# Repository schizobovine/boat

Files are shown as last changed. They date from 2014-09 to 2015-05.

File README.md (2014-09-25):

Battery Operated Arduino Thermometer (B.O.A.T.)
==============

Similar to Moteino/Anarduino, an Arduino-compatiblish uC board with onboard
RFM69CW, SMA edge connector, and i2c thermometer chip. Powered by CR2032
batter. No onboard voltage regulation, so don't plug into 5V unless you need a
doorstop (the ATMega will be fine, but the wireless card and thermometer are
only specced for 3.6V max).

Yes, there are many Arduino-based wireless sensor projects out there. Most use
2.4GHz radios, however, and that's getting to be an awful crowded band,
especially if one lives in an apartment building. To avoid making that even
worse, I choose to use one of the other ISM bands, specifically 433MHz. This is
normally used for stuff like garage door openers and the like. (Also military
radar, which makes for some hilarious anecdotes).

Anyway, I decided to build my own board for this, even if other designs exist
that are probably better in just about every way. But this one is my own
special snowflake. It even has a cow on it! (Don't judge me.)

Licensed under the Creative Commons Attribution-ShareAlike License
(CC-BY-SA-4.0)

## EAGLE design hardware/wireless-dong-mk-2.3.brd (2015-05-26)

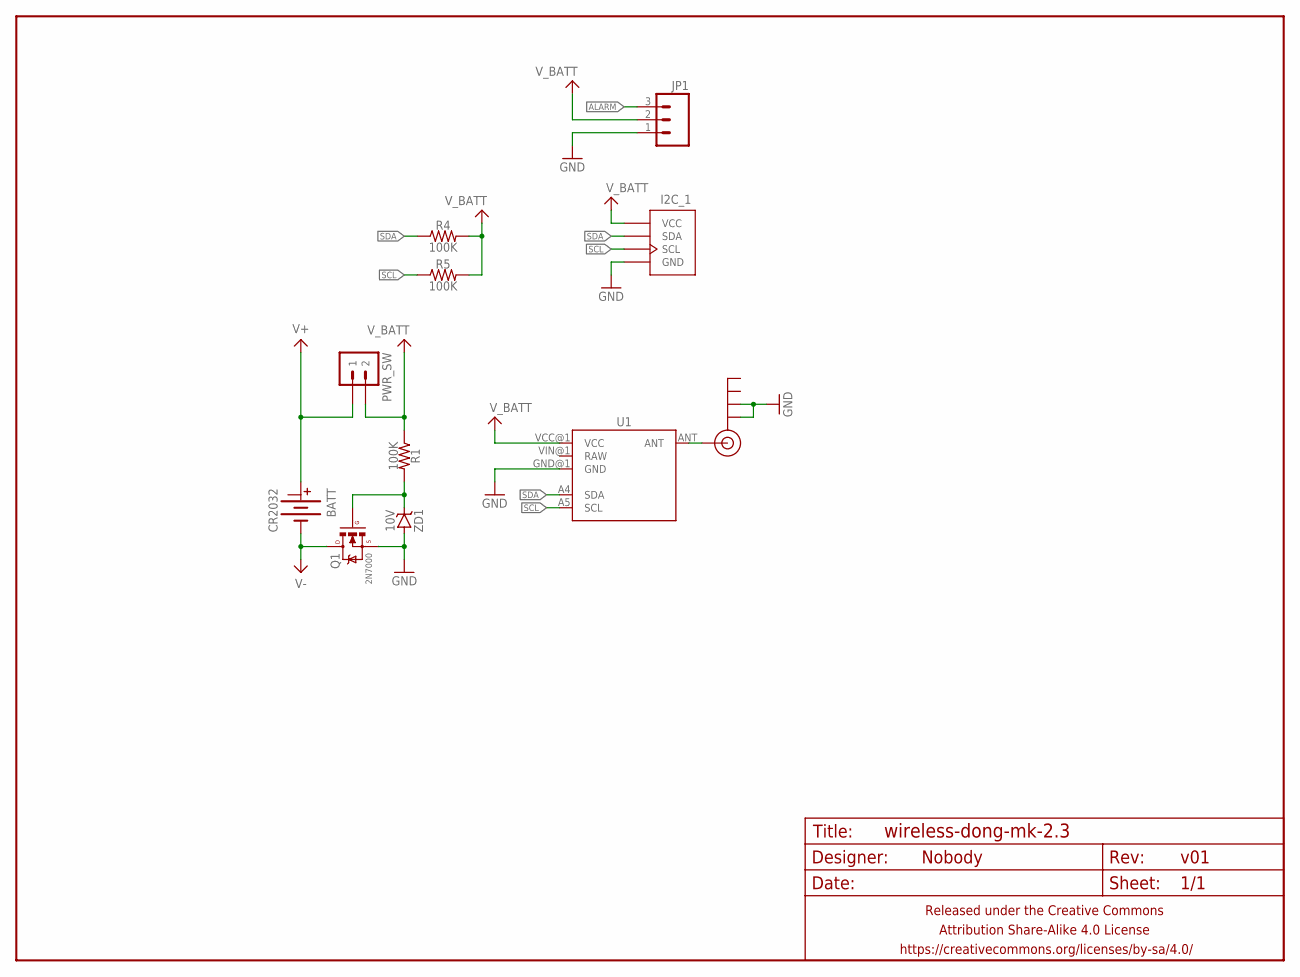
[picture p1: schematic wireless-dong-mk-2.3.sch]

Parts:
ANT: SMA_EDGE; SMA-EDGE
BATT: CR2032; BATTCON_20MM_MINE_STAHPIT
FRAME1: FRAME-LETTERNO_PACKAGE; DUMMY
I2C_1: M04-I2CJST-4-PH-RA-CENTERED; 1X04-JST-PH-RA-PTH-I2C-CENTERED
JP1: M03JST-PTH; JST-3-PH-RA-PTH
PWR_SW: M02PTH-CENTERED; 1X02-CENTER
Q1: 2N7000; SOT23
R1, R4, R5: 100K; R0805
U1: MOTEINO_BOAT
ZD1: 10V; SOT23

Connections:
ALARM: JP1.3
GND: ANT.GND@0 (GND), ANT.GND@1 (GND), I2C_1.1 (GND), JP1.1, Q1.2 (S), U1.GND@1 (GND), ZD1.1 (A), ZD1.2 (A)
unnamed: Q1.1 (G), R1.2, ZD1.3 (C)
unnamed: ANT.SIG (SIGNAL), U1.ANT
SCL: I2C_1.4 (SCL), R5.1, U1.A5 (SCL)
SDA: I2C_1.3 (SDA), R4.1, U1.A4 (SDA)
V+: BATT.TOP@1 (+), PWR_SW.1
V-: BATT.BOTTOM (-), Q1.3 (D)
V_BATT: I2C_1.2 (VCC), JP1.2, PWR_SW.2, R1.1, R4.2, R5.2, U1.VCC@1 (VCC)

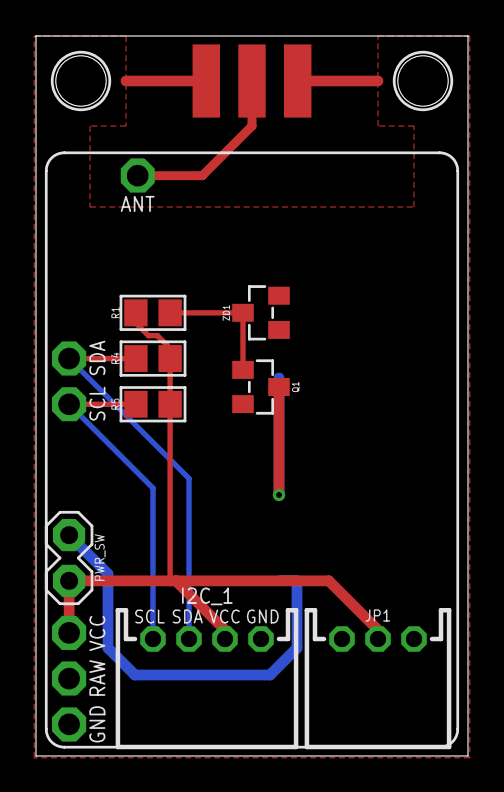
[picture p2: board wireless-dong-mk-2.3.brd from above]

Board: 2 copper layers, 24.0 x 40.0 mm, 12 parts (1 on the bottom side), 8 nets.

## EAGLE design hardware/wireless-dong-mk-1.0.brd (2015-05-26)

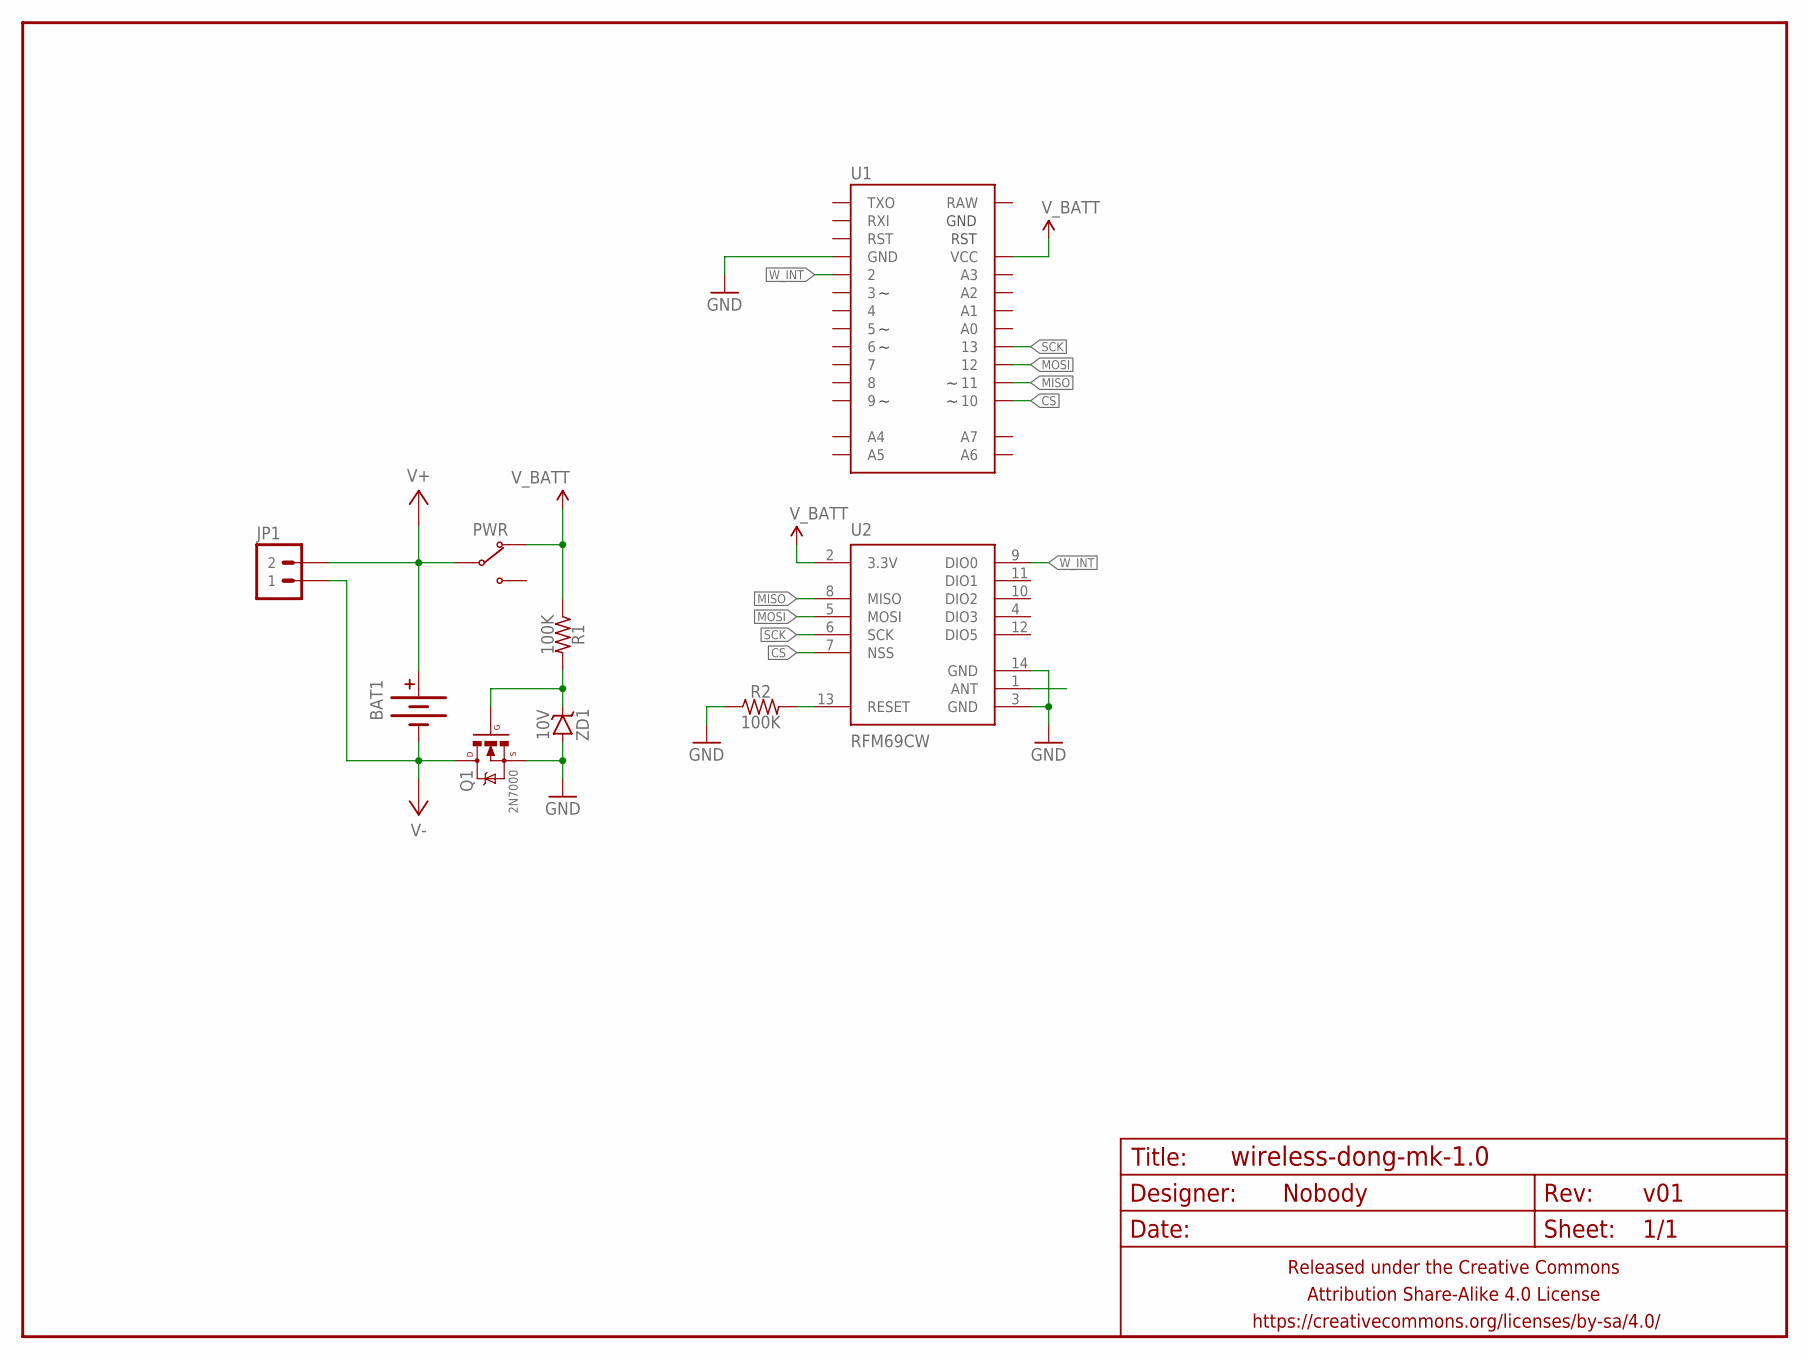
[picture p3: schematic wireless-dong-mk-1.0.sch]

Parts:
BAT1: BATTERYAA; BATTERY-AA
FRAME1: FRAME-LETTERNO_PACKAGE; DUMMY
JP1: M02PTH-CENTERED-R+; 1X02-CENTER-R+
PWR: SWITCH-SPDTPTH-RA-2.54MM; SPDT-RA-2.54MM
Q1: 2N7000; SOT23
R1, R2: 100K; R0603
U1: ARDUINO-PRO-MINI-NO-FTDIARDUINO_PRO_MINI_NO_FTDI_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; ARDUINO_PRO_MINI_NO_FTDI_NO_SILK
U2: RFM69CW; RFM69CW-XXXS2
ZD1: 10V; SOT23

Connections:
CS: U1.10, U2.7 (NSS)
GND: Q1.2 (S), R2.1, U1.GND@1 (GND), U1.GND@2 (GND), U2.3 (GND), U2.14 (GND), ZD1.1 (A), ZD1.2 (A)
MISO: U1.11, U2.8 (MISO)
MOSI: U1.12, U2.5 (MOSI)
unnamed: Q1.1 (G), R1.2, ZD1.3 (C)
unnamed: R2.2, U2.13 (RESET)
SCK: U1.13, U2.6 (SCK)
V+: BAT1.PWR@1 (+), BAT1.PWR@2 (+), JP1.2, PWR.2 (COM)
V-: BAT1.GND@1 (-), BAT1.GND@2 (-), JP1.1, Q1.3 (D)
V_BATT: PWR.1 (NC), R1.1, U1.VCC, U2.2 (3.3V)
W_INT: U1.2, U2.9 (DIO0)

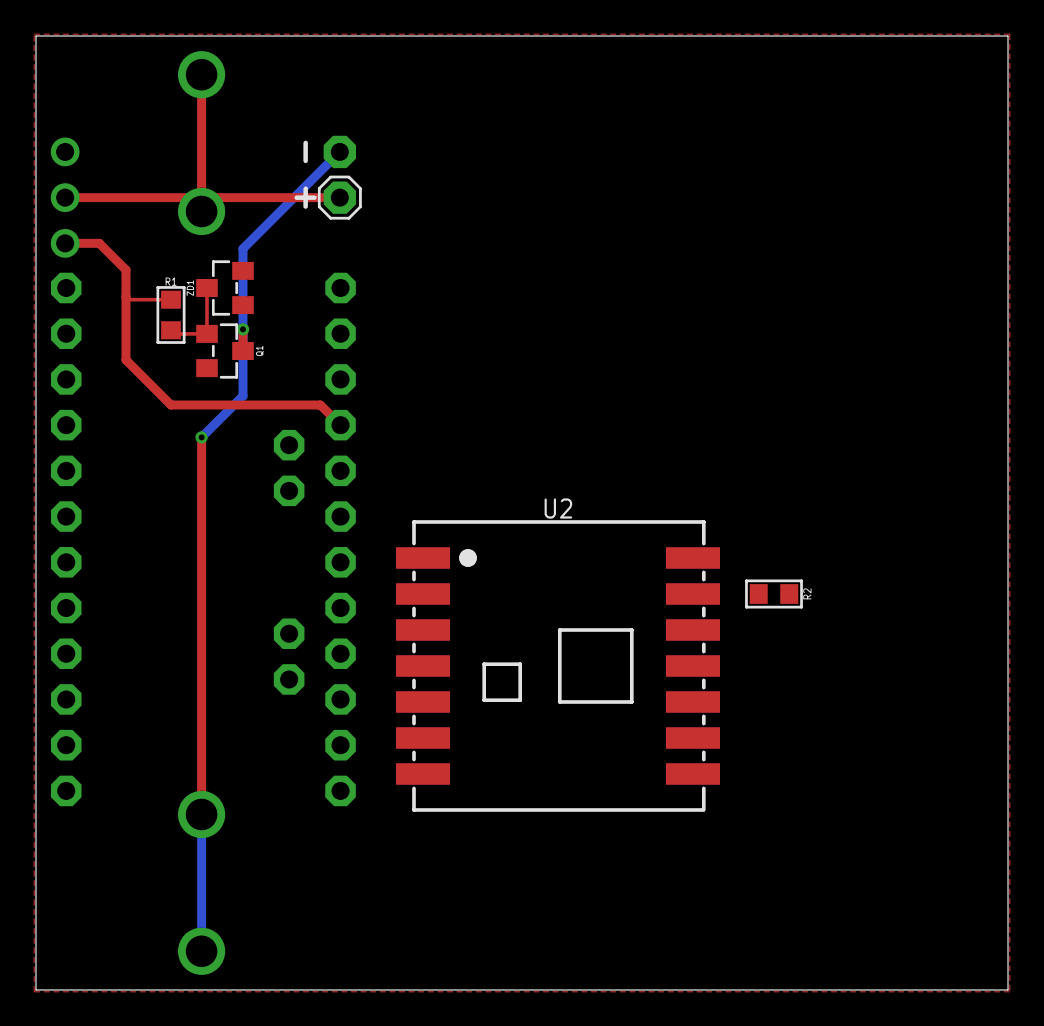
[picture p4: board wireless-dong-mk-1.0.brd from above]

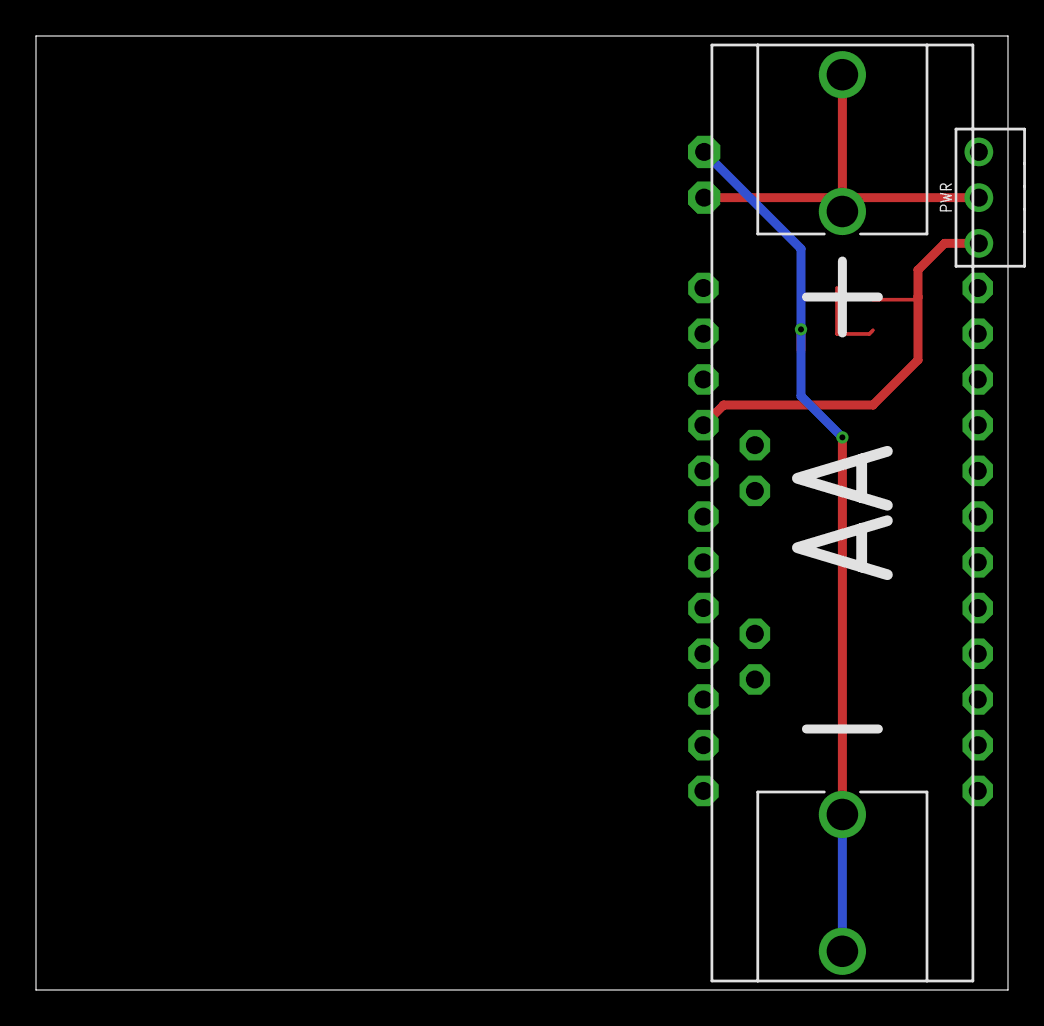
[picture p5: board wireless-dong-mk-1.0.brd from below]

Board: 2 copper layers, 54.0 x 53.0 mm, 10 parts (2 on the bottom side), 11 nets.

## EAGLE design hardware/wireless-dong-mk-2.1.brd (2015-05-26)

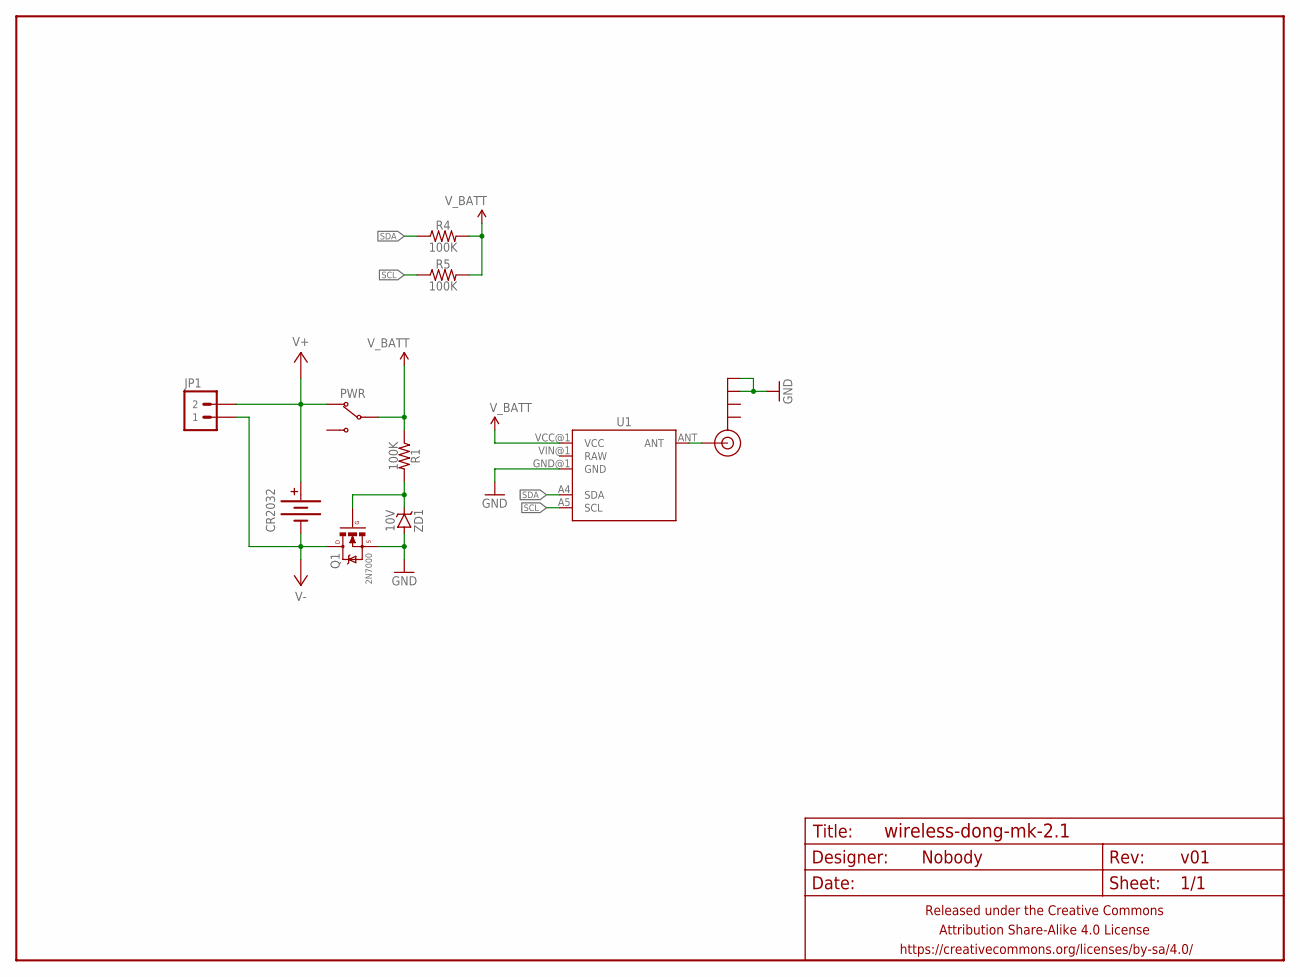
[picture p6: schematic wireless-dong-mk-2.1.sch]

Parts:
ANT: SMA_EDGE; SMA-EDGE
CR2032: BATTERY20PTH_TOPLOAD; BATTCON_20MM_PTH_TOPLOAD
FRAME1: FRAME-LETTERNO_PACKAGE; DUMMY
JP1: M02PTH-CENTERED-R+; 1X02-CENTER-R+
PWR: SWITCH-SPDTPTH-RA-2.54MM; SPDT-RA-2.54MM
Q1: 2N7000; SOT23
R1, R4, R5: 100K; R0603
U1: MOTEINO_BOAT
ZD1: 10V; SOT23

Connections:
GND: ANT.GND@2 (GND), ANT.GND@3 (GND), Q1.2 (S), U1.GND@1 (GND), ZD1.1 (A), ZD1.2 (A)
unnamed: Q1.1 (G), R1.2, ZD1.3 (C)
unnamed: ANT.SIG (SIGNAL), U1.ANT
SCL: R5.1, U1.A5 (SCL)
SDA: R4.1, U1.A4 (SDA)
V+: CR2032.+, JP1.2, PWR.1 (NC)
V-: CR2032.-, JP1.1, Q1.3 (D)
V_BATT: PWR.2 (COM), R1.1, R4.2, R5.2, U1.VCC@1 (VCC)

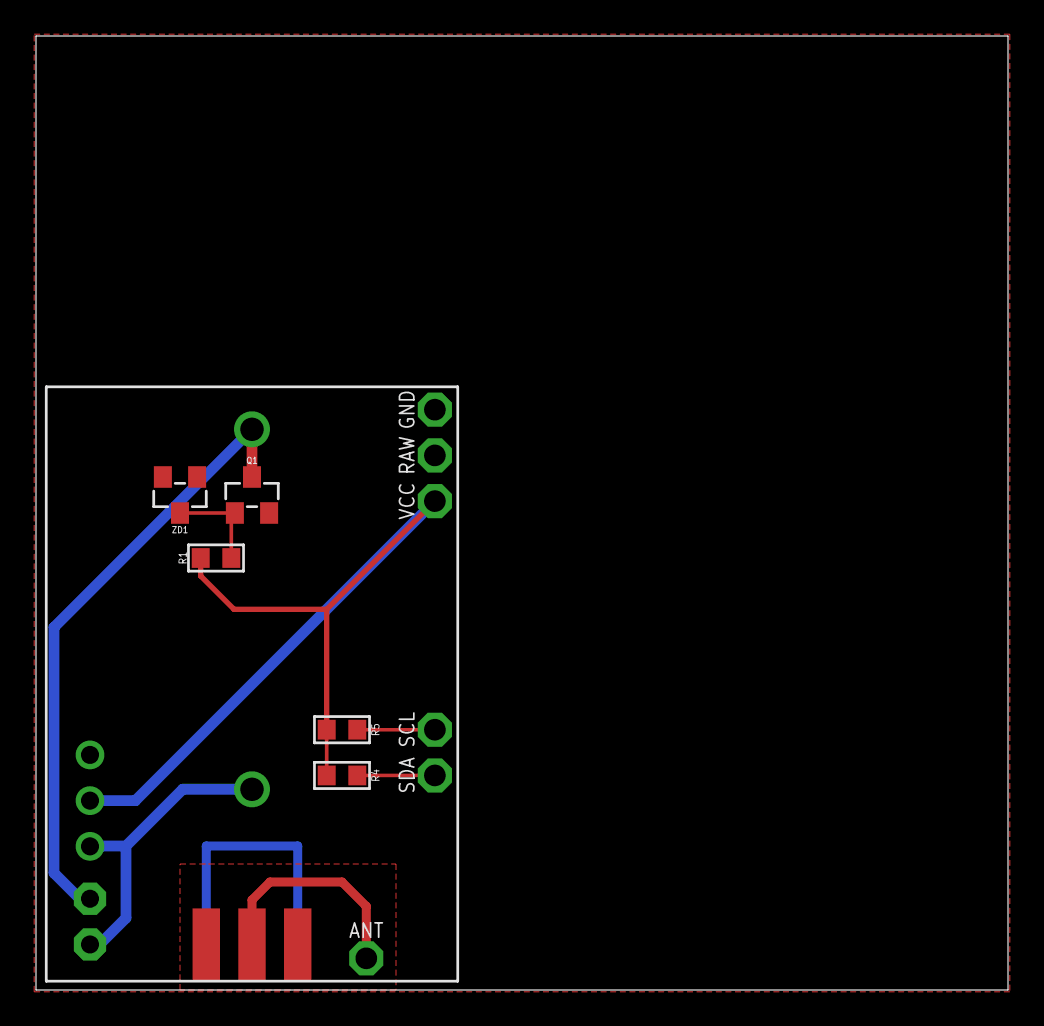
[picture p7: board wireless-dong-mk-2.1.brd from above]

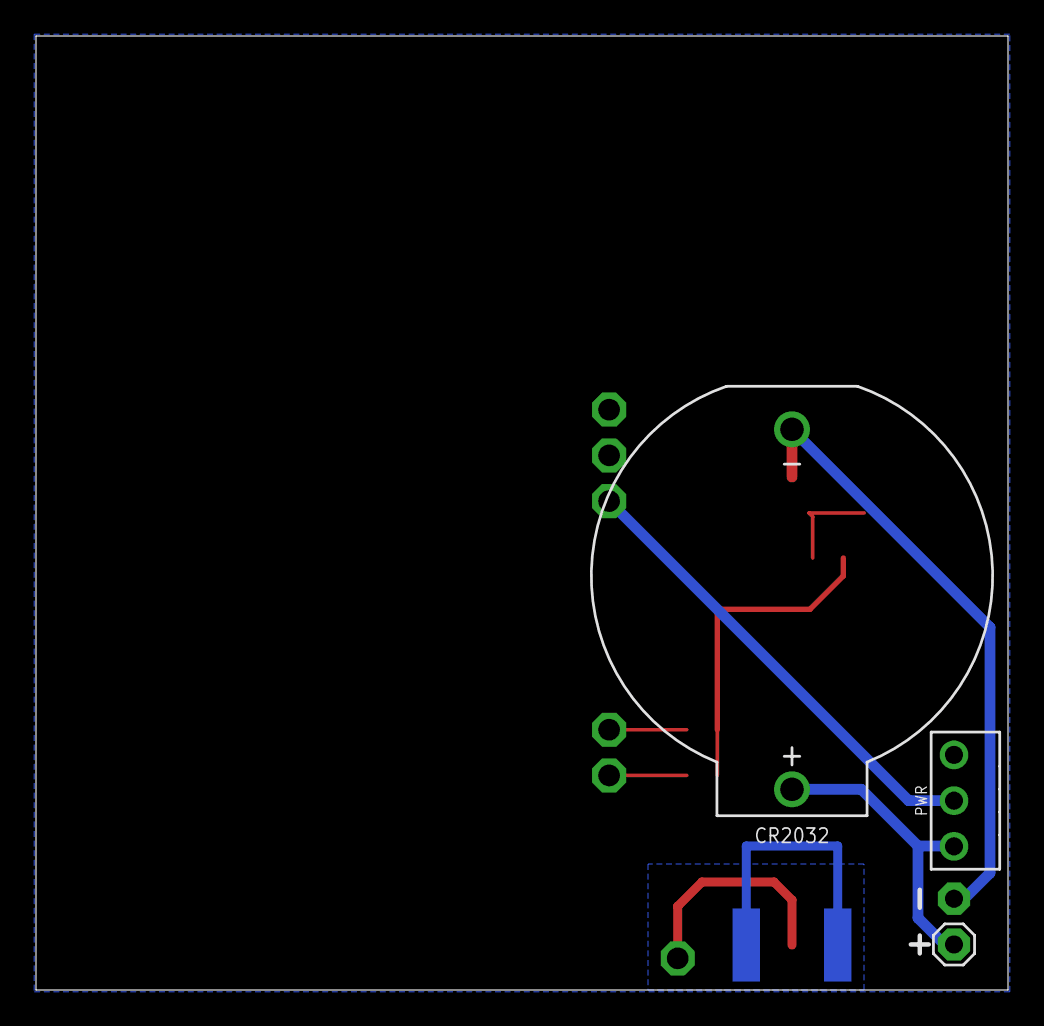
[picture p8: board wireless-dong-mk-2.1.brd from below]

Board: 2 copper layers, 54.0 x 53.0 mm, 11 parts (3 on the bottom side), 8 nets.

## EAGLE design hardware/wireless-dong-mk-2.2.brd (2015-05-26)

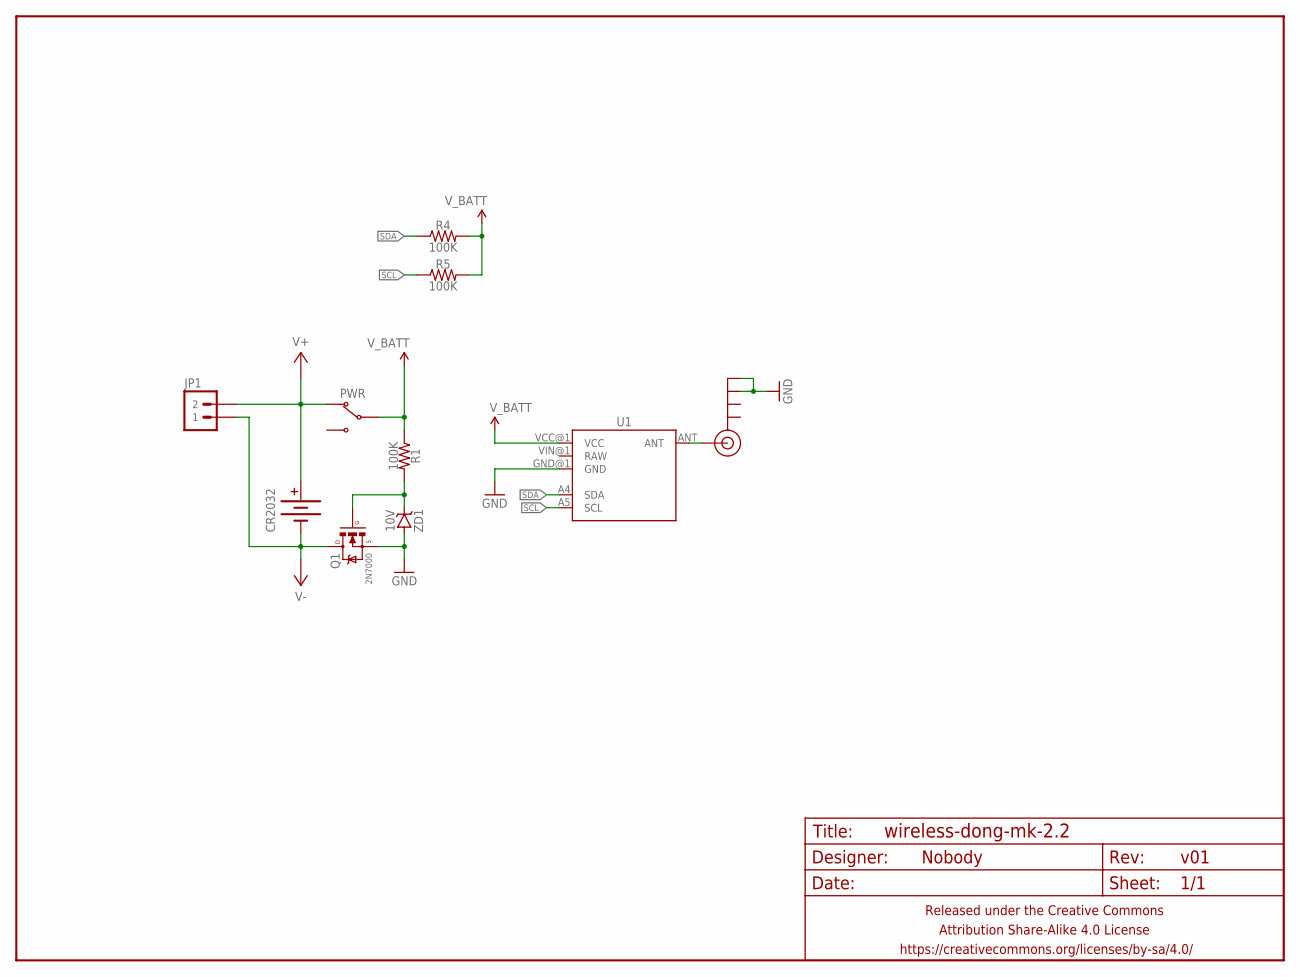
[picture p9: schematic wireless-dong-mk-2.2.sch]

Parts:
ANT: SMA_EDGE; SMA-EDGE
CR2032: BATTERY20PTH_TOPLOAD; BATTCON_20MM_PTH_TOPLOAD
FRAME1: FRAME-LETTERNO_PACKAGE; DUMMY
JP1: M02PTH-CENTERED-R+; 1X02-CENTER-R+
PWR: SWITCH-SPDTPTH-RA-2.54MM; SPDT-RA-2.54MM
Q1: 2N7000; TO-92-AMMO
R1, R4, R5: 100K; RESISTOR-AXIAL-PTH-7.62MM
U1: MOTEINO_BOAT
ZD1: 10V; DIODE-ZENNER-7.62MM

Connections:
GND: ANT.GND@2 (GND), ANT.GND@3 (GND), Q1.1 (S), U1.GND@1 (GND), ZD1.A
unnamed: Q1.2 (G), R1.P$2 (2), ZD1.K (C)
unnamed: ANT.SIG (SIGNAL), U1.ANT
SCL: R5.P$1 (1), U1.A5 (SCL)
SDA: R4.P$1 (1), U1.A4 (SDA)
V+: CR2032.+, JP1.2, PWR.1 (NC)
V-: CR2032.-, JP1.1, Q1.3 (D)
V_BATT: PWR.2 (COM), R1.P$1 (1), R4.P$2 (2), R5.P$2 (2), U1.VCC@1 (VCC)

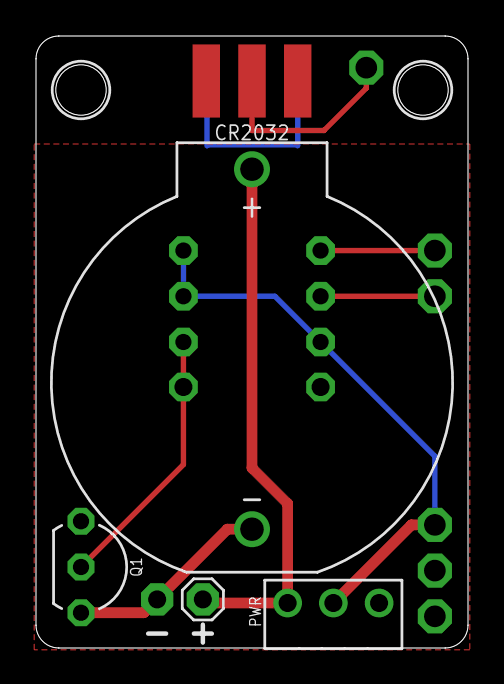
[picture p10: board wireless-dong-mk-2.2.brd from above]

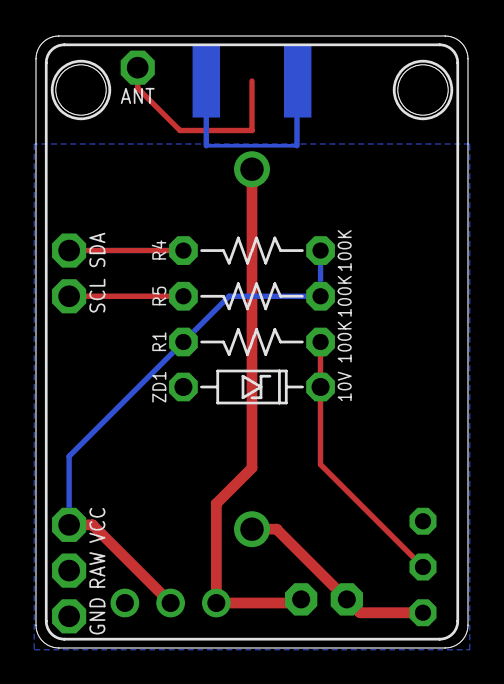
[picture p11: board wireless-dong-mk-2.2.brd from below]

Board: 2 copper layers, 24.0 x 34.0 mm, 11 parts (5 on the bottom side), 8 nets.

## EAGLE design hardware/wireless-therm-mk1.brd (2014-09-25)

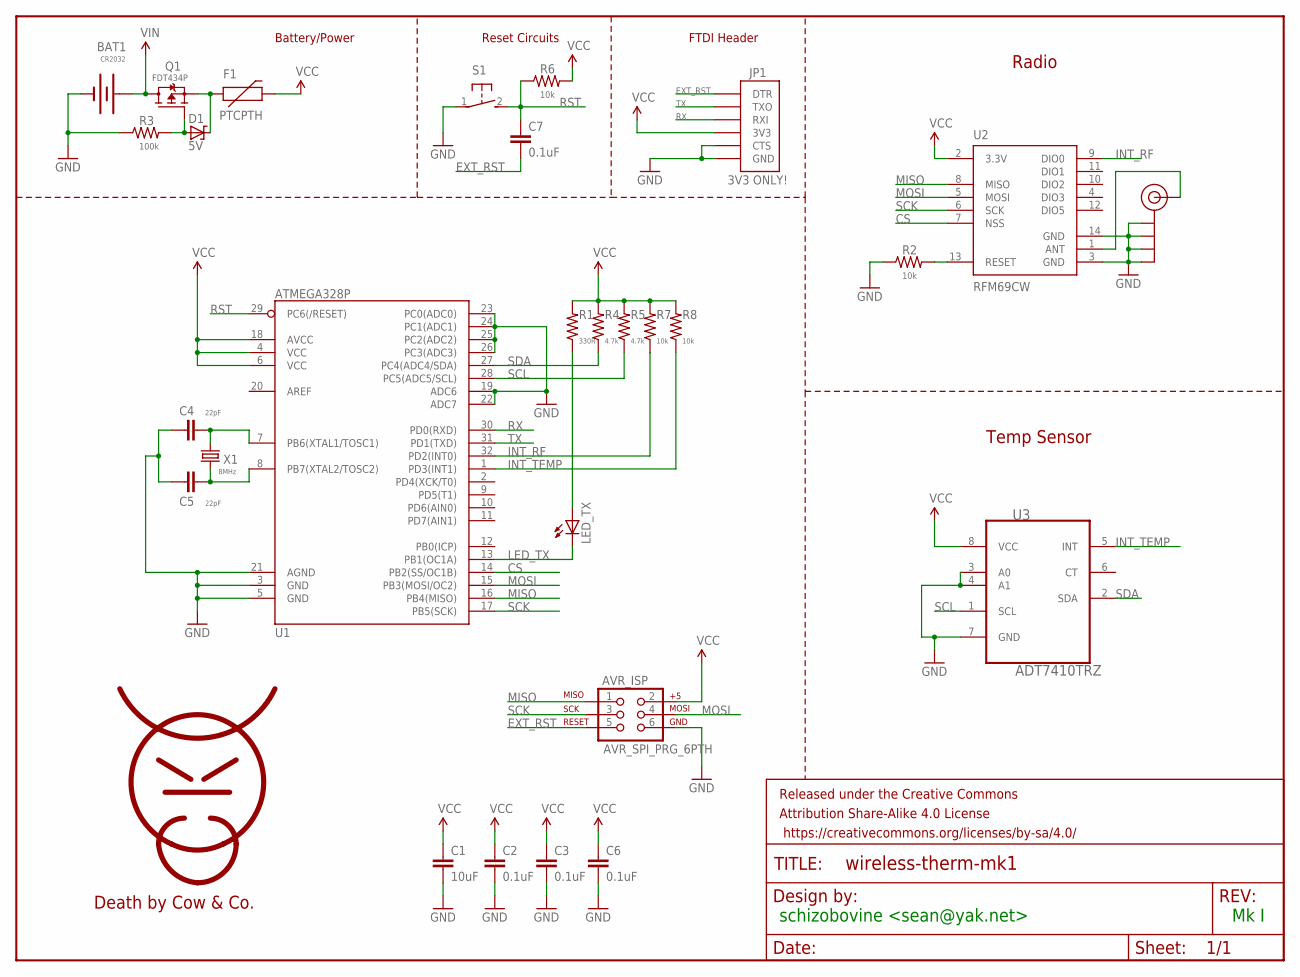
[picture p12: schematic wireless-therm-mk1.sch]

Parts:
AVR_ISP: AVR_SPI_PRG_6PTH; 2X3
BAT1: CR2032; BATTCON_20MM
C1: 10uF; C050-025X075
C2, C3, C6, C7: 0.1uF; C025-024X044
C4, C5: 22pF; C025-025X050
D1: 5V; DO34Z7
F1: PTCPTH; PTC
FRAME1: FRAME-LETTER; CREATIVE_COMMONS
JP1: 3V3 ONLY!; FTDI_3V3
LED_TX: GREEN; LED3MM
Q1: FDT434P; SOT223
R1: 330R; 0204/5
R2, R6, R7, R8: 10k; 0204/5
R3: 100k; 0204/5
R4, R5: 4.7k; 0204/5
S1: DTS-3
SMA_CON: SMA_EDGE; SMA-EDGE
U1: ATMEGA328P; TQFP32-08
U2: RFM69CW; RFM69CW-XXXS2
U3: ADT7410TRZ; SOIC127P600X175-8N
U$4: COW
X1: 8MHz; HC49U70

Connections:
ANT: SMA_CON.SIG (SIGNAL), U2.1 (ANT)
CS: U1.14 (PB2(SS/OC1B)), U2.7 (NSS)
EXT_RST: AVR_ISP.5, C7.2, JP1.P$1 (DTR)
GND: AVR_ISP.6, BAT1.2 (-), C1.2, C2.2, C3.2, C4.1, C5.1, C6.2, JP1.P$5 (CTS), JP1.P$6 (GND), R2.1, R3.1, S1.1, SMA_CON.GND@0 (GND), SMA_CON.GND@1 (GND), SMA_CON.GND@2 (GND), SMA_CON.GND@3 (GND), U1.3 (GND), U1.5 (GND), U1.19 (ADC6), U1.21 (AGND), U1.22 (ADC7), U1.23 (PC0(ADC0)), U1.24 (PC1(ADC1)), U1.25 (PC2(ADC2)), U1.26 (PC3(ADC3)), U2.3 (GND), U2.14 (GND), U3.3 (A0), U3.4 (A1), U3.7 (GND)
INT_RF: R7.1, U1.32 (PD2(INT0)), U2.9 (DIO0)
INT_TEMP: R8.1, U1.1 (PD3(INT1)), U3.5 (INT)
LED_TX: LED_TX.K (C), U1.13 (PB1(OC1A))
MISO: AVR_ISP.1, U1.16 (PB4(MISO)), U2.8 (MISO)
MOSI: AVR_ISP.4, U1.15 (PB3(MOSI/OC2)), U2.5 (MOSI)
unnamed: LED_TX.A, R1.1
unnamed: R2.2, U2.13 (RESET)
unnamed: D1.C, F1.P$1 (1), Q1.3 (S)
unnamed: C4.2, U1.7 (PB6(XTAL1/TOSC1)), X1.2
unnamed: C5.2, U1.8 (PB7(XTAL2/TOSC2)), X1.1
unnamed: D1.A, Q1.1 (G), R3.2
RST: C7.1, R6.1, S1.2, U1.29 (PC6(/RESET))
RX: JP1.P$3 (RXI), U1.30 (PD0(RXD))
SCK: AVR_ISP.3, U1.17 (PB5(SCK)), U2.6 (SCK)
SCL: R5.1, U1.28 (PC5(ADC5/SCL)), U3.1 (SCL)
SDA: R4.1, U1.27 (PC4(ADC4/SDA)), U3.2 (SDA)
TX: JP1.P$2 (TXO), U1.31 (PD1(TXD))
VCC: AVR_ISP.2, C1.1, C2.1, C3.1, C6.1, F1.P$2 (2), JP1.P$4 (3V3), R1.2, R4.2, R5.2, R6.2, R7.2, R8.2, U1.4 (VCC), U1.6 (VCC), U1.18 (AVCC), U2.2 (3.3V), U3.8 (VCC)
VIN: BAT1.1 (+), BAT1.3 (+), Q1.2 (D), Q1.4 (D)

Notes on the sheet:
schizobovine <sean@yak.net>
Mk I
Battery/Power
Reset Circuits
FTDI Header
Radio
Temp Sensor



Board: 2 copper layers, 74.0 x 34.0 mm, 32 parts (2 on the bottom side), 23 nets.

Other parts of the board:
LOGO1: OSHW-LOGOS; OSHW-LOGO-S
U$3: OSHW-LOGO-L

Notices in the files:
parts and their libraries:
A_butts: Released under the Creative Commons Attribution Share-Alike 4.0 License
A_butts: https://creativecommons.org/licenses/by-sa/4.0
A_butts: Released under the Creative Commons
